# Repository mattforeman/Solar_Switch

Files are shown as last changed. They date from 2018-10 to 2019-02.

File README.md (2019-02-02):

# Solar Switch

Code compiles in Arduino IDE and layout files open in Eagle.

This was designed as a cheap/easy/hackable method of controlling how solar and AC mains power is routed. By default, this system monitors a solar battery bank voltage,
when it detects that the batteries are low, it switches the load to AC mains to allow the batteries to recharge - at which time it switches back to solar power.

This was mostly designed for hobbyists who have a only a few solar panels and want to power their projects/computers from solar, but do not have a big enough system
to run their load 24/7.

It was designed using the ATMEGA328P in the Arduino IDE and a compatible Arduino shield header. This allows the user to add any number of accesories to the system.
Some of the ideas that I had in mind were: Sd card logging and Wifi/GSM notifications.

The most current iteration is seen here:
Prototype 3

Our first Arduino prototype board is seen here:
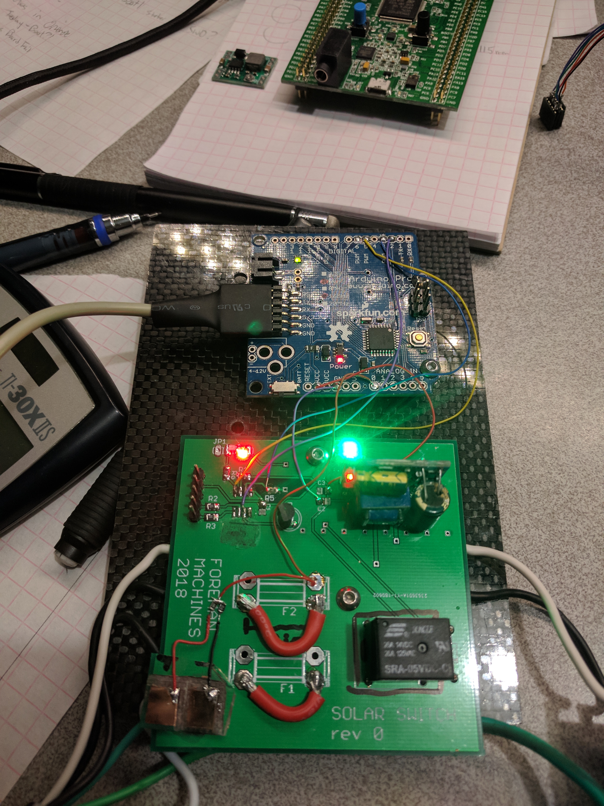
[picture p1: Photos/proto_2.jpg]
Prototype 2


Board Layout:
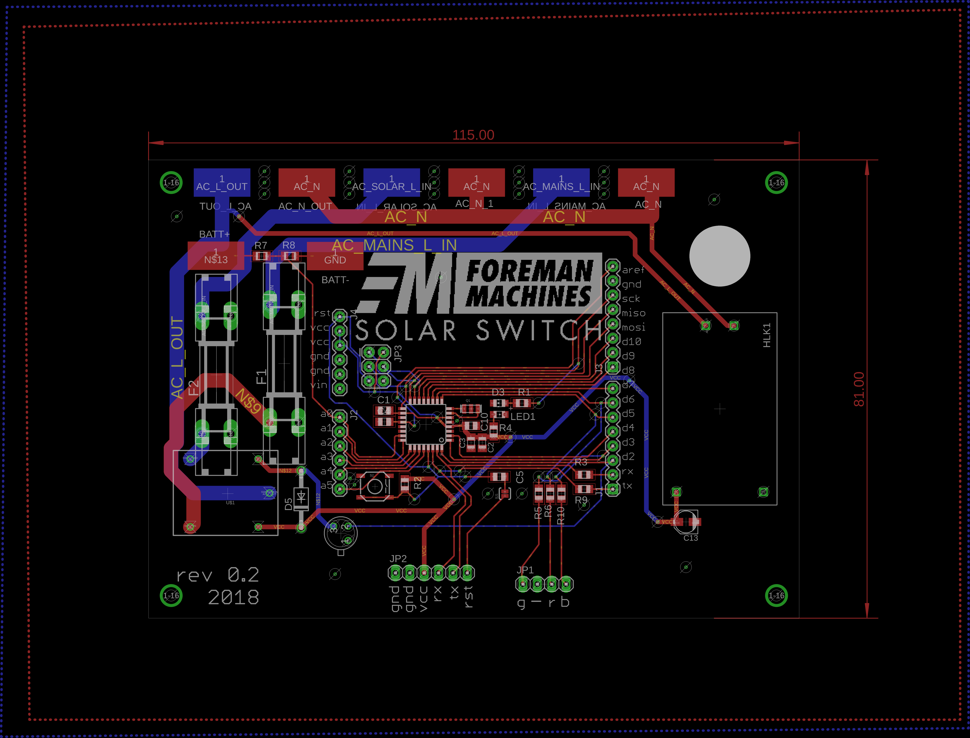
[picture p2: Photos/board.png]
Layout


Current schematic is seen here:
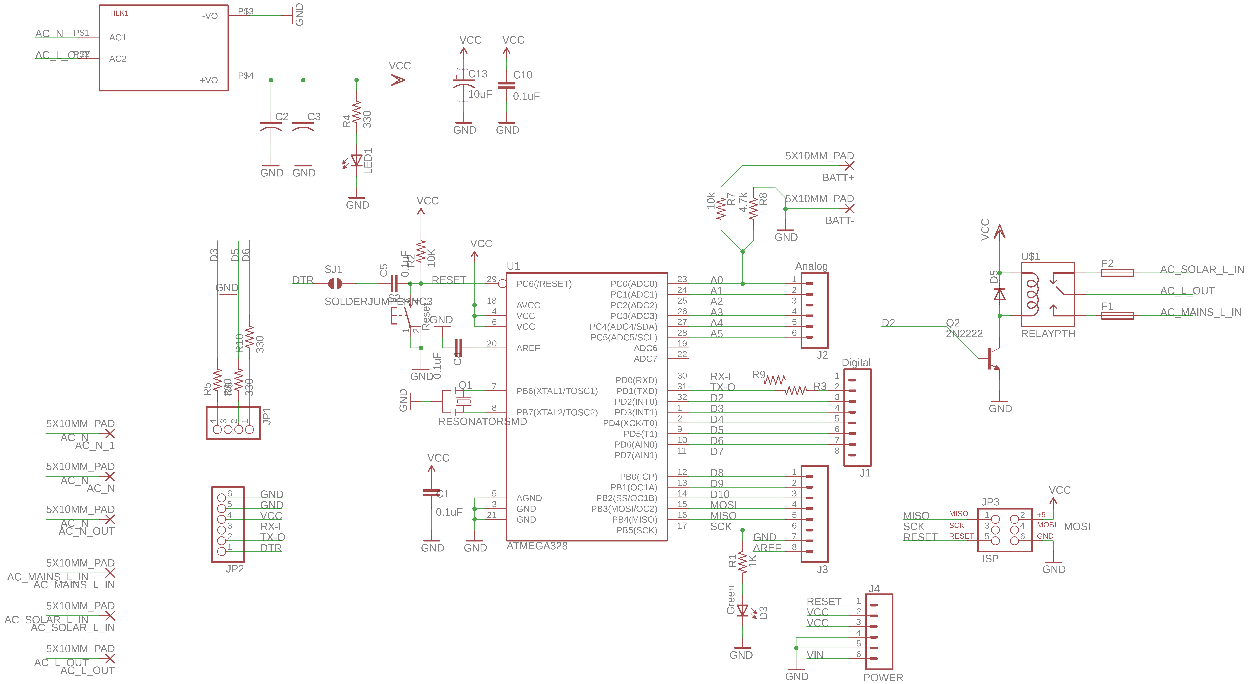
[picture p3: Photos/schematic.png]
Schematic


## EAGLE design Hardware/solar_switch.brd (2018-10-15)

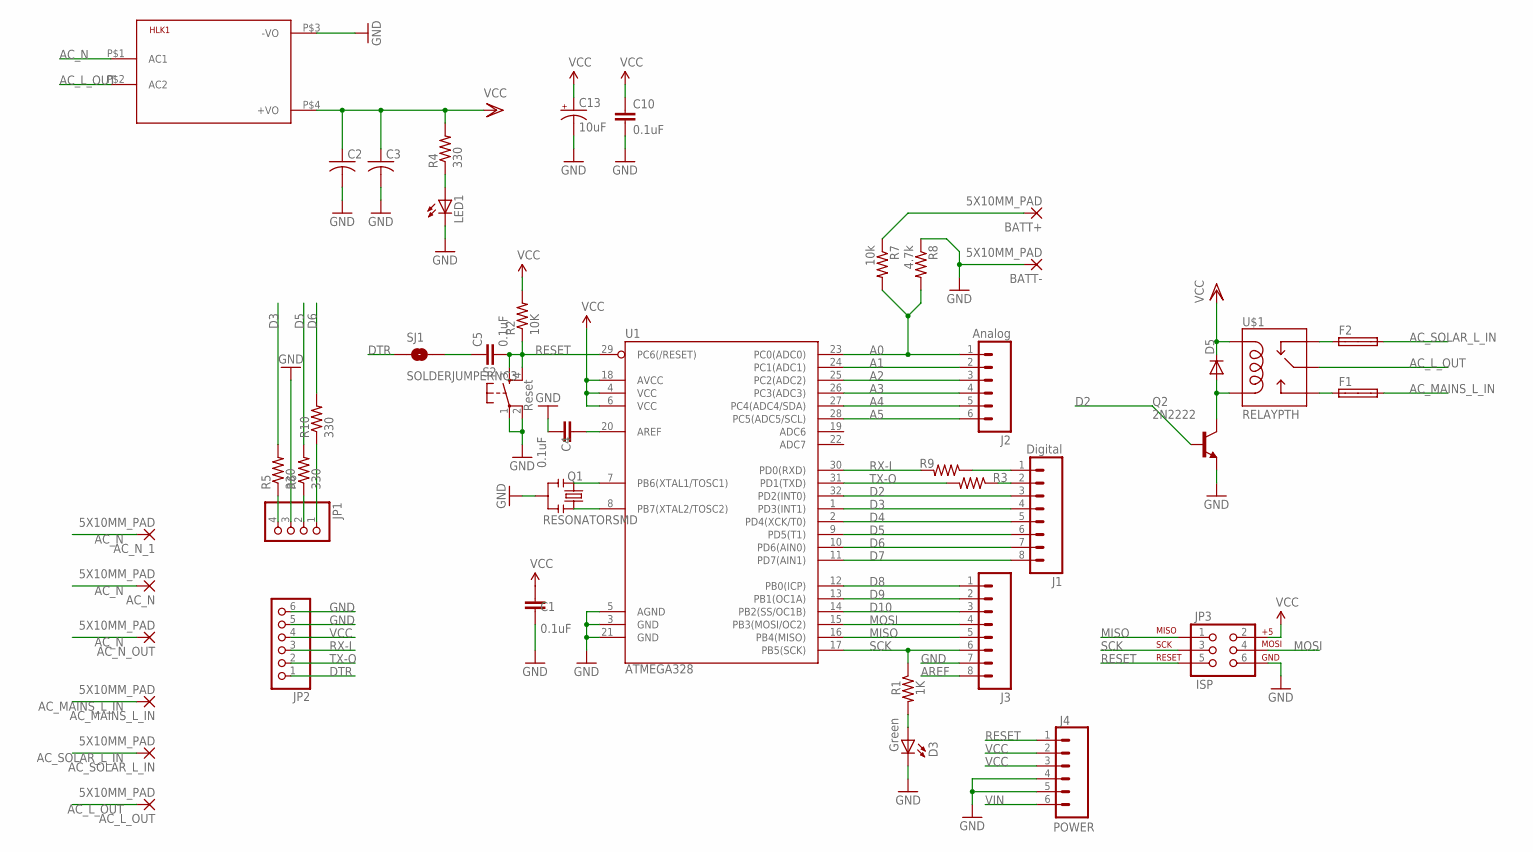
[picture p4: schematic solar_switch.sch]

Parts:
AC_L_OUT: 5X10MM_PAD; SMD5-10
AC_MAINS_L_IN: 5X10MM_PAD; SMD5-10
AC_N: 5X10MM_PAD; SMD5-10
AC_N_1: 5X10MM_PAD; SMD5-10
AC_N_OUT: 5X10MM_PAD; SMD5-10
AC_SOLAR_L_IN: 5X10MM_PAD; SMD5-10
BATT+: 5X10MM_PAD; SMD5-10
BATT-: 5X10MM_PAD; SMD5-10
C1, C4, C5, C10: 0.1uF; C0805
C2, C3: C-USC0805K; C0805K
C13: 10uF; PANASONIC_B
D3: Green; CHIP-LED0805
D5: 1N4004; DO41-10
F1, F2: SHKOG
HLK1: HLK-PM013W; HLK-PM01
J1: Digital; 1X08
J2: Analog; 1X06
J3: M081X08; 1X08
J4: POWER; 1X06
JP1: PINHD-1X4; 1X04
JP2: PINHD-1X6; 1X06
JP3: ISP; 2X3
LED1: LEDCHIPLED_0805; CHIPLED_0805
Q1: RESONATORSMD; RESONATOR-SMD
Q2: 2N2222; TO18
R1: 1K; R0805
R2: 10K; R0805
R3, R9: 220; R0805
R4, R5, R6, R10: 330; R0805
R7: 10k; M0805
R8: 4.7k; M0805
S2: Reset; TACTILE_SWITCH_SMD
SJ1: SOLDERJUMPERNC3; SJ_2S-NOTRACE
U1: ATMEGA328; TQFP32-08
U$1: RELAYPTH; SRD-05VDC-SL-C

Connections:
A0: J2.1, R7.2, R8.2, U1.23 (PC0(ADC0))
A1: J2.2, U1.24 (PC1(ADC1))
A2: J2.3, U1.25 (PC2(ADC2))
A3: J2.4, U1.26 (PC3(ADC3))
A4: J2.5, U1.27 (PC4(ADC4/SDA))
A5: J2.6, U1.28 (PC5(ADC5/SCL))
AC_L_OUT: AC_L_OUT.1, HLK1.P$2 (AC2), U$1.SWCOMMON
AC_MAINS_L_IN: AC_MAINS_L_IN.1, F1.2A
AC_N: AC_N.1, AC_N_1.1, AC_N_OUT.1, HLK1.P$1 (AC1)
AC_SOLAR_L_IN: AC_SOLAR_L_IN.1, F2.2A
AREF: C4.2, J3.8, U1.20 (AREF)
D2: J1.3, Q2.2 (B), U1.32 (PD2(INT0))
D3: J1.4, R5.2, U1.1 (PD3(INT1))
D4: J1.5, U1.2 (PD4(XCK/T0))
D5: J1.6, R6.2, U1.9 (PD5(T1))
D6: J1.7, R10.2, U1.10 (PD6(AIN0))
D7: J1.8, U1.11 (PD7(AIN1))
D8: J3.1, U1.12 (PB0(ICP))
D9: J3.2, U1.13 (PB1(OC1A))
D10: J3.3, U1.14 (PB2(SS/OC1B))
DTR: JP2.1, SJ1.1
GND: BATT-.1, C1.1, C2.2, C3.2, C4.1, C10.2, C13.-, D3.C, HLK1.P$3 (-VO), J3.7, J4.4, J4.5, JP1.3, JP2.5, JP2.6, JP3.6, LED1.C, Q1.2, Q2.1 (E), R8.1, S2.1, S2.2, U1.3 (GND), U1.5 (AGND), U1.21 (GND)
MISO: J3.5, JP3.1, U1.16 (PB4(MISO))
MOSI: J3.4, JP3.4, U1.15 (PB3(MOSI/OC2))
unnamed: D3.A, R1.2
unnamed: C5.1, SJ1.2
unnamed: Q1.1, U1.8 (PB7(XTAL2/TOSC2))
unnamed: Q1.3, U1.7 (PB6(XTAL1/TOSC1))
unnamed: LED1.A, R4.1
unnamed: JP1.1, R10.1
unnamed: F2.1A, U$1.SWCLOSED (SWCLOSE)
unnamed: F1.1A, U$1.SWOPEN
unnamed: JP1.4, R5.1
unnamed: JP1.2, R6.1
unnamed: D5.A, Q2.3 (C), U$1.COIL0
unnamed: BATT+.1, R7.1
RESET: C5.2, J4.1, JP3.5, R2.1, S2.3, S2.4, U1.29 (PC6(/RESET))
RX-I: JP2.3, R9.2, U1.30 (PD0(RXD))
RX-IP: J1.2, R3.1
SCK: J3.6, JP3.3, R1.1, U1.17 (PB5(SCK))
TX-O: JP2.2, R3.2, U1.31 (PD1(TXD))
TX-OP: J1.1, R9.1
VCC: C1.2, C2.1, C3.1, C10.1, C13.+, D5.C, HLK1.P$4 (+VO), J4.2, J4.3, JP2.4, JP3.2, R2.2, R4.2, U1.4 (VCC), U1.6 (VCC), U1.18 (AVCC), U$1.COIL1
VIN: J4.6

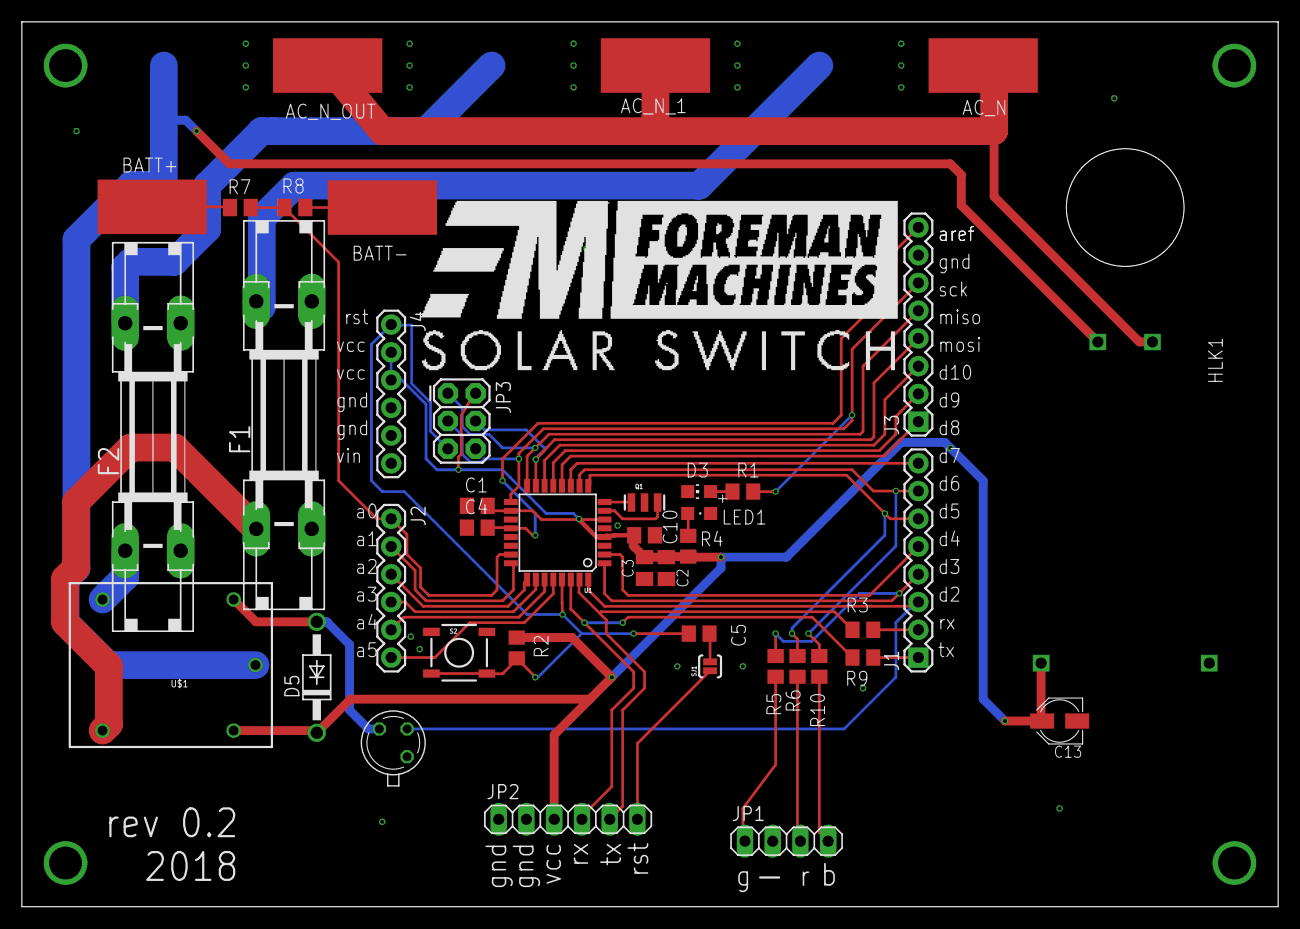
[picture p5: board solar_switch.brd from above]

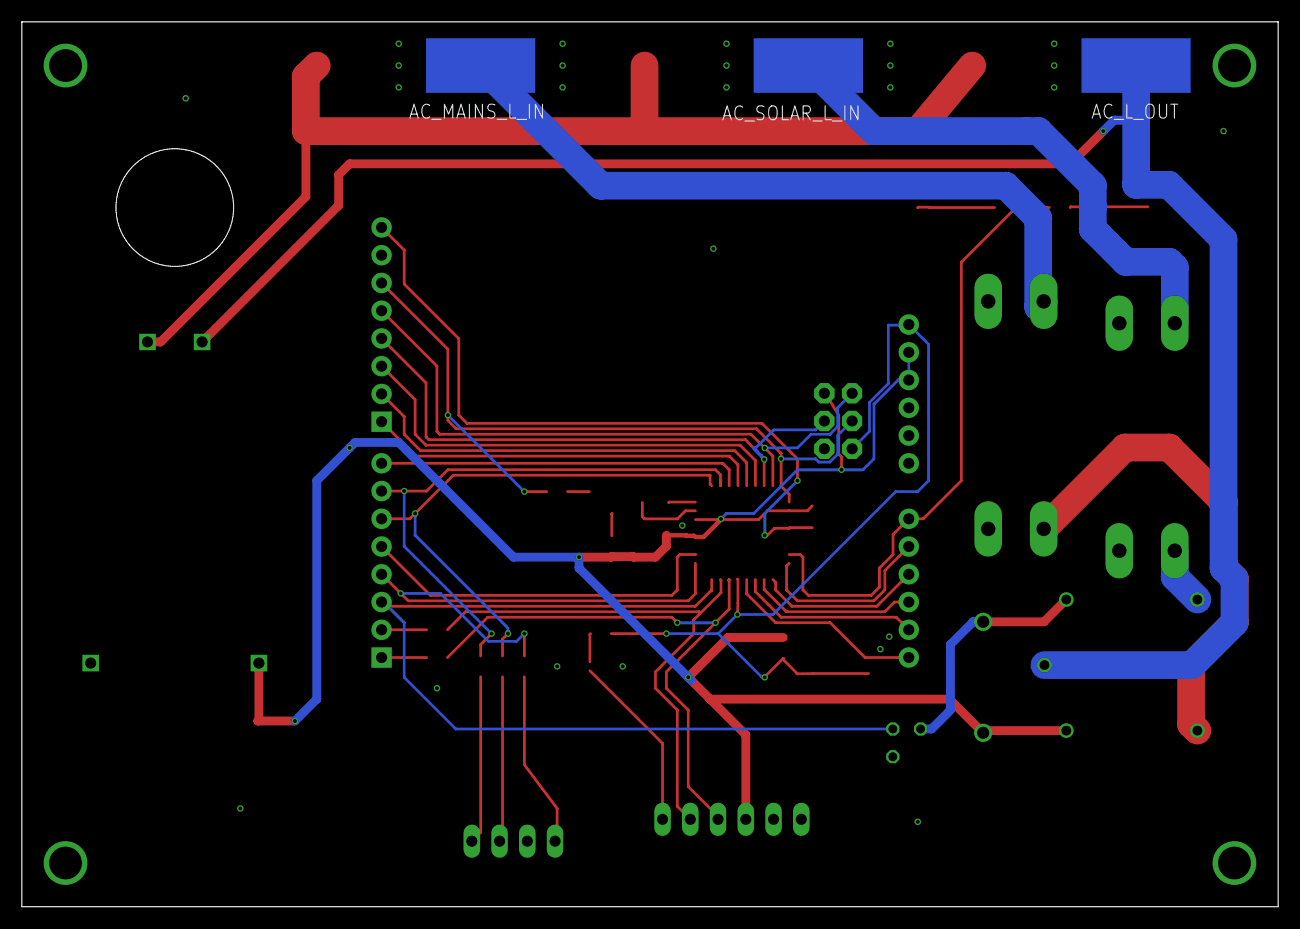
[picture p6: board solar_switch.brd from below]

Board: 2 copper layers, 115.0 x 81.0 mm, 44 parts (3 on the bottom side), 43 nets.

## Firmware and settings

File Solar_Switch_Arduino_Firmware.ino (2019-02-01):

/*
 Firmware v0.1
*/

#define RELAY_PIN 2

#define LED_G_PIN 3
#define LED_R_PIN 5 
#define LED_B_PIN 6

#define SOLAR_PRIORITY 7 //LOW == Switch on (pin pulled high w/ pull-up resistor, pulled low when shorted)
#define MAINS_PRIORITY 8

#define BATT_IN_PIN A0

#define BATT_CALIBRATE 65 //

#define ABS_MIN_VOLTAGE 3.0
#define ABS_MAX_VOLTAGE 16.0
#define NEED_CHARGE_VOLTAGE 13.1
#define FULL_VOLTAGE 14.0

bool source_current; //1 - Solar | 0 - Mains
bool source_prev;  //needed?

bool charge_flag = 0;
int battery_voltage;


void setup() {
  // setup io
  pinMode(RELAY_PIN, OUTPUT);
  pinMode(LED_R_PIN, OUTPUT);
  pinMode(LED_G_PIN, OUTPUT);
  pinMode(LED_B_PIN, OUTPUT);
  
  pinMode(BATT_IN_PIN, INPUT);
  pinMode(SOLAR_PRIORITY, INPUT);
  pinMode(MAINS_PRIORITY, INPUT);

  //start serial monitor for debug
  Serial.begin(9600);
}

//***MAIN LOOP***//
void loop() {
  //check if there is a source priority before main program
  while (digitalRead(SOLAR_PRIORITY) == 0){solar_priority();}
  while (digitalRead(MAINS_PRIORITY) == 0){mains_priority();}

  //no priority - normal operation
  normal_operation();
}

void solar_priority(){
  Serial.println("Solar Priority - Relay OFF");
  delay(250);
  
  digitalWrite(RELAY_PIN, LOW);

  digitalWrite(LED_R_PIN, LOW);
  digitalWrite(LED_G_PIN, HIGH);
  digitalWrite(LED_B_PIN, LOW);

  //allows low battery voltage check
  battery_voltage = check_voltage();
  
  delay(100);
}

void mains_priority(){
  Serial.println("Mains Priority - Relay ON");
  delay(250);
  
  digitalWrite(RELAY_PIN, HIGH);

  digitalWrite(LED_R_PIN, LOW);
  digitalWrite(LED_G_PIN, LOW);
  digitalWrite(LED_B_PIN, HIGH);
  
  delay(100);
}

void normal_operation(){
  battery_voltage = check_voltage();

  //battery less than NEEDS_CHARGE_VOLTAGE, so switch to mains and let battery charge
  if(battery_voltage <= (NEED_CHARGE_VOLTAGE * 100)){
    Serial.println("Battery is charging - Mains supply");
    delay(250);
    
    charge_flag = 1;
    digitalWrite(RELAY_PIN, HIGH);

    digitalWrite(LED_R_PIN, LOW);
    digitalWrite(LED_G_PIN, LOW);
    digitalWrite(LED_B_PIN, HIGH);
    
    delay(100);
  }
  
  else if(battery_voltage > (NEED_CHARGE_VOLTAGE * 100)){
    
    if(charge_flag == 0){
      //battery normal range and charged - solar power
      Serial.println("Battery Normal - Solar power");
      delay(250);
      
      digitalWrite(RELAY_PIN, LOW);

      digitalWrite(LED_R_PIN, LOW);
      digitalWrite(LED_G_PIN, HIGH);
      digitalWrite(LED_B_PIN, LOW);
      
      delay(100);
    }

    //above empty battery, but needs to bring up to float voltage
    else if(charge_flag == 1){
      if(battery_voltage < (FULL_VOLTAGE * 100)){
        Serial.print("Above ");
        Serial.print(NEED_CHARGE_VOLTAGE);
        Serial.print(" but still charging to ");
        Serial.print(FULL_VOLTAGE);

        delay(250);
      }
      //battery fully charged
      else if(battery_voltage >= (FULL_VOLTAGE * 100)){

        Serial.println("Done charging, switching to solar");
        
        charge_flag = 0;

        //done charging, switch to solar
        digitalWrite(RELAY_PIN, LOW);

        digitalWrite(LED_R_PIN, LOW);
        digitalWrite(LED_G_PIN, HIGH);
        digitalWrite(LED_B_PIN, LOW);
      }
    }

      //battery just finished charging - solar power
    else if( charge_flag == 1 && battery_voltage >= (FULL_VOLTAGE * 100)){
      Serial.println("Battery Charged - Solar power");
      delay(250);
      charge_flag = 0;
      digitalWrite(RELAY_PIN, LOW);

      digitalWrite(LED_R_PIN, LOW);
      digitalWrite(LED_G_PIN, HIGH);
      digitalWrite(LED_B_PIN, LOW);
      
      delay(100);
    }
    
    //if charge flag previously on, battery needs more time to charge (float voltage)
    else{ //(charge_flag == 1 && battery_voltage < (FULL_VOLTAGE * 100)){
      //do nothing, battery still needs charging
      delay(100);
    }
  }
}

float check_voltage(){
  float battery_in = analogRead(BATT_IN_PIN);
  Serial.print("Raw Analog In: ");
  Serial.println(battery_in);
  
  float battery_voltage = (battery_in / BATT_CALIBRATE)*100; //avoiding float math

  Serial.print("Integer voltage: ");
  Serial.println(battery_voltage);

  Serial.print("Battery Voltage: ");
  Serial.println(battery_voltage / 100);
  //Serial.print(".");
  //Serial.println(battery_voltage % 100);
  delay(250);
  //error state
  if(battery_voltage <= (ABS_MIN_VOLTAGE * 100) || battery_voltage >= (ABS_MAX_VOLTAGE * 100)){
    
    while(1){ //force reset
    
      digitalWrite(LED_G_PIN, LOW);      
      digitalWrite(LED_R_PIN, LOW);
      digitalWrite(LED_B_PIN, HIGH);
      delay(250);
      digitalWrite(LED_R_PIN, HIGH);
      digitalWrite(LED_B_PIN, LOW);
      delay(250);
    }
  }
  return battery_voltage;
}
